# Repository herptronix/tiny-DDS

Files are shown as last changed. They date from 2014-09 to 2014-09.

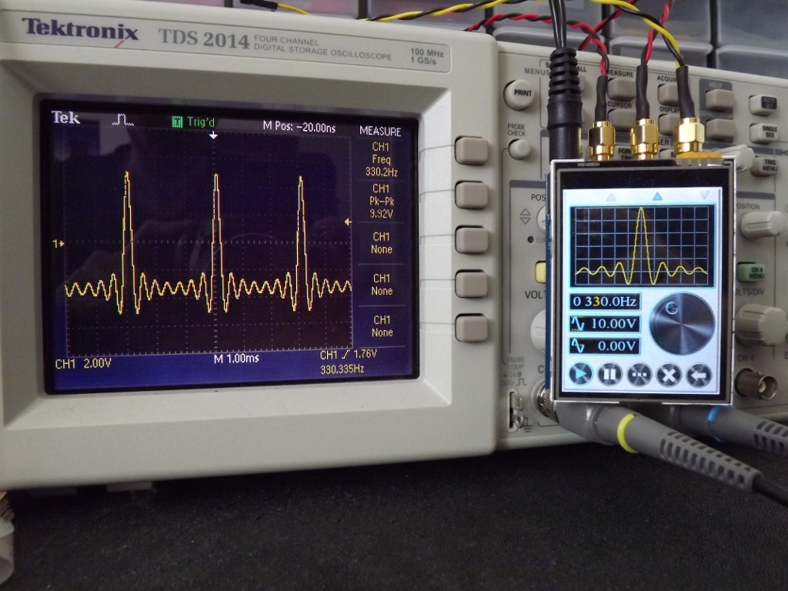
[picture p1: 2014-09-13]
documentation/dds.jpg

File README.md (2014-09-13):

Tiny DDS
================

Open source (hardware & software) DDS generator, based on:
 - smart TFT module
 - AD9834
 - LM7171 fast amplifier

Small video: https://www.youtube.com/watch?v=Hllg0D2UqWg
Some explanations (french only): http://herptronix.blogspot.fr/2014/08/tiny-dds.html



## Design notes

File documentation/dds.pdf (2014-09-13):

The homemade function generator is a quite common project on the internet. We can find different ways to do it:

- The quick & dirty way based on a DDS module bought on eBay
- The analog version based on a MAX038 / XR2206
- The “clean” way based on a FPGA and a fast DAC (e.g. http://www.circuitben.net/node/14)
- The software way (e.g. Arduino + R/2R DAC)

From my side, I wanted a small one which could fits my needs without being too expensive. According to me, such generator should at least:

- Be easy to use
- Output a signal from 1Vpp to 10Vpp (+/-5V), from 0 to 1MHz
- Have a low profile
- Without electric hazard (shall work on a 12V DC)

Choosing the DDS chip

I first started to look for a cheap DDS chip on eBay; you have to be careful because most of DDS chips have only a sinusoidal output. Since I also want a triangular output, I have chosen the AD9834. According to its datasheet, this component is able to output a frequency of 37.5MHz from a clock of 75MHz… But do not expect a clean waveform at such frequency: without an internal PLL, this signal would be defined by only 2 points.

From my personal experience, I consider that a waveform shall be defined by 10-20 points to be well restituted. Relying on a 75MHz clock, the maximal output frequency would be 7.5MHz… This is not a very good performance for a professional equipment (even if the cheapest generators do not go above 4MHz), but it is quite reasonable for a hobbyist project.

The AD9834 can be found at $5 on eBay.

Amplitude control

The amplitude of the AD9834 can be controlled through different ways:

- Constant amplitude of 1Vpp (by default on most COTS), by wiring a resistor between the FS_ADJUST pin and the ground: this is quite annoying because an additional external amplifier will be need to set the amplitude to a desired level.
- Variable amplitude, by wiring a potentiometer between the FS_ADJUST pin and the ground: this solution is really easy to implement, but it will not allow a software management needed, for example, by the amplitude modulation.
- Software variable amplitude, by wiring a DAC to the FS_ADJUST pin. This solution is a bit more complex, but it will allow to implement some useful functionalities. I choose this way.

The amplitude will be set by the microcontroller of the smart TFT module (PIC32MX795). Unlike the other manufacturers (Atmel, ST…), Microchip did not include a DAC on their $10 chip… An external DAC is needed (an AD5310 found on eBay for $0.8 – 10 bit / SPI, SOT23-6 package).
A small voltage divider is put between the DAC and the FS_ADJUST pin in order to transform the 0-3.3V of the DAC into 0-1.2V handled by the AD9834:

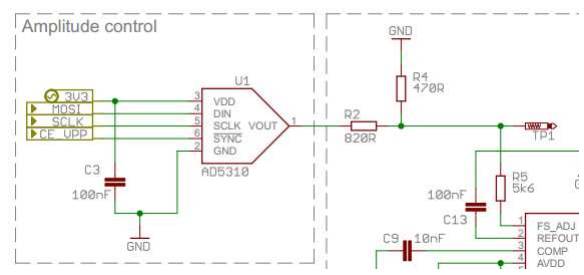
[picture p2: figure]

Notice: the logical levels are reversed: the minimal amplitude is reached when the DAC output is 3V3 and the maximal amplitude is reached when the DAC output is 0V.

AC coupling

The AD9834 generates a signal with a non-null offset, variable according to the amplitude. At this point, this offset is very annoying and shall be removed. Two possible ways:
- A high pass filter (a simple RC filter): this solution ensures an ideal AC coupling, but is problematic for the low frequency signals (a huge RC filter would be needed for frequencies below 100Hz)
- A differential amplifier: it is possible with the AD9834 because this component already has a differential output (IOUT / IOUTB pins). This solution makes the AC coupling effective even for very low frequencies, even for a DC signal. Therefore, the AC coupling will not be “ideal”: a small offset will be injected, and possibly some additional distortions due to the tolerance of the components (OPAMP & resistors). Nevertheless, it remains the best way according to me.

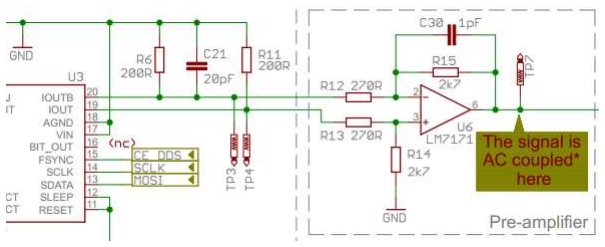
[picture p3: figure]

The ratio R15/R12 is set such as the maximal voltage outputted by U6 is +/-3.3V.

Offset control
Nothing difficult here: we just have to generate a DC signal between -3.3V and +3.3V. I use another AD5310 with a small OPAMP:

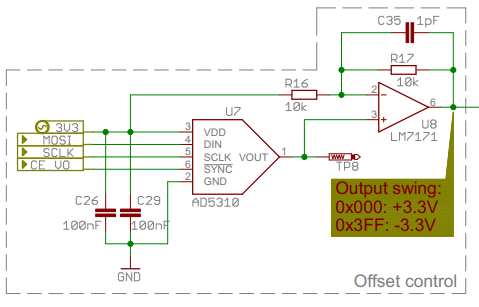
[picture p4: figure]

Notice: here again, the logical levels are reversed: the minimal offset is reached when the DAC output is +3.3V and the maximal offset is reached when the DAC output is 0V.

Final stage
Here, we have 2 signals: the one coming from the DDS (between -3.3V and +3.3V, AC coupled) and the one coming from the offset control (between -3.3V and +3.3V too). We just have to mix these 2 signals and amplify them to get a +/-5V output:

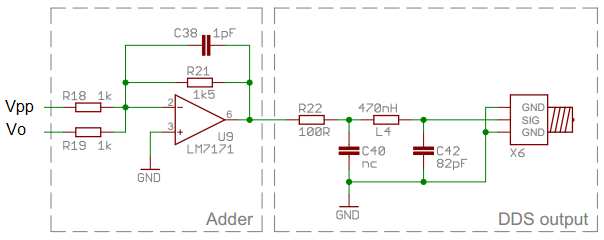
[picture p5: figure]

The LM7171 is able to output more than 100mA; nevertheless, the current is limited through a 100R resistor. A small LC filter is also implemented before the main output for filtering the 75MHz clock residual.

PWM output
Nothing complex here: a simple CMOS gate for buffering the PWM output of the microcontroller. I tried to use a fast comparator on the triangular output of the DDS, but the jitter was too important; I finally gave up this solution.

Analog input

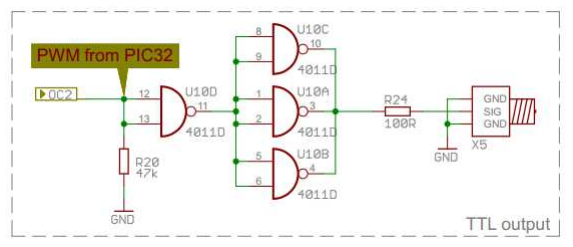
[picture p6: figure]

Very minimalist… A simple resistor for limiting the input current, and a common Pi filter. The sampling frequency is not very high (~ 1KHz) because the internal ADC of the microcontroller is also used by the touchscreen inside an ISR.

Power supply / regulators

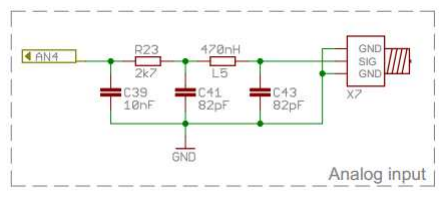
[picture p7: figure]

The generator is powered by a standard 12V plug. Some switching regulators produce the 5V (for the smart TFT module) and the +/-7V (used by the analog stage). The 3.3V comes directly from the smart TFT. The LT1616 are an expensive components on Farnell, but I found these on eBay for $0.8. Notice that any buck regulator should do the job here (+5V@200mA, +/-7V@200mA).

PCB
The whole schematic can be easily routed in a small PCB (smaller than a credit card). The PCB is composed of 2 layouts, with a common GND plan. The LM7171 shall be routed with care: due to its topology (fast OPAMP – 400MHz), a bad layout will make it oscillate. For this reason, I also add a footprint for a small 1pF capacitor: if the layout is not correct, I should be able to limit the oscillations with it.

Assembling the board
The PCBs (from SeeedFusion):

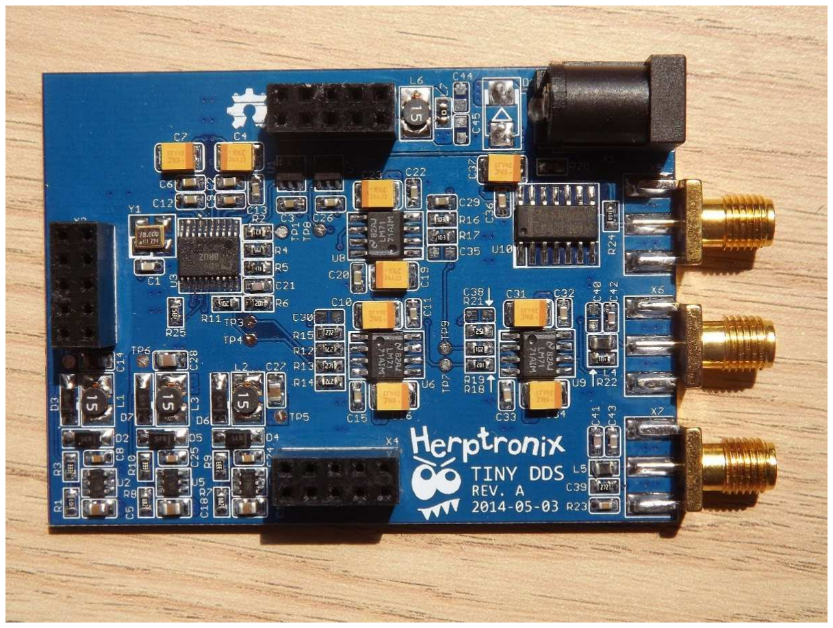
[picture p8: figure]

The finished board:

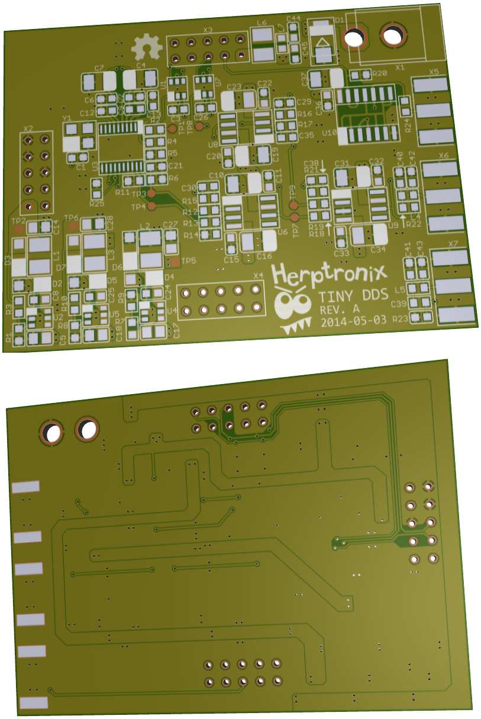
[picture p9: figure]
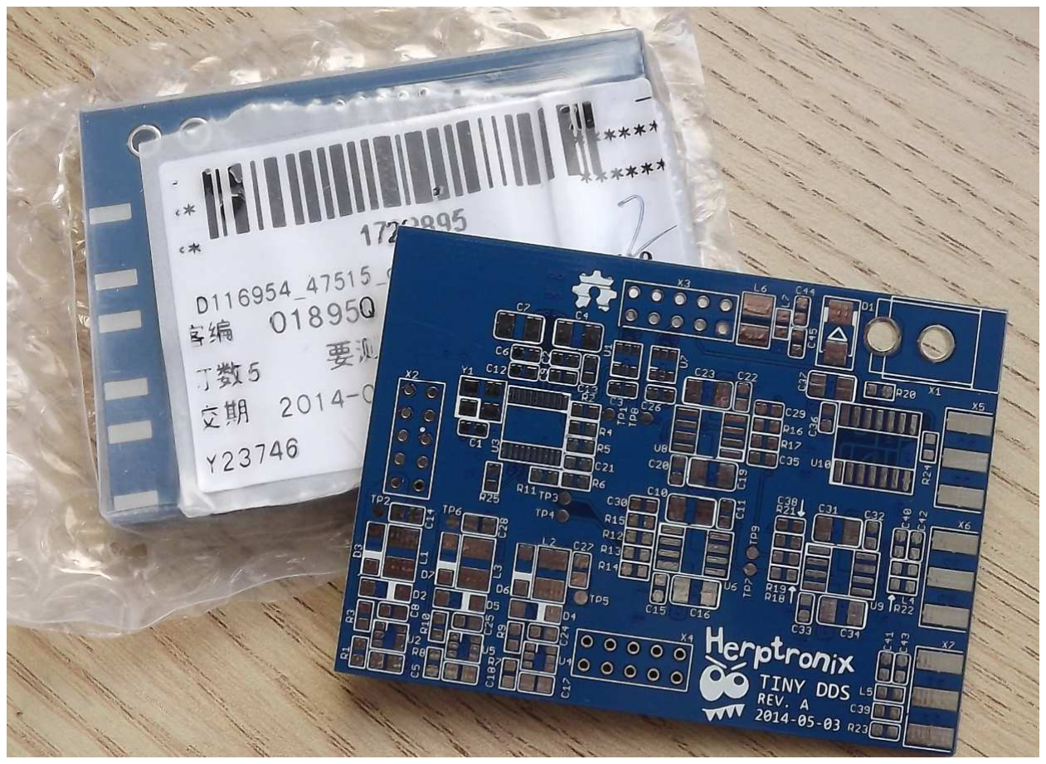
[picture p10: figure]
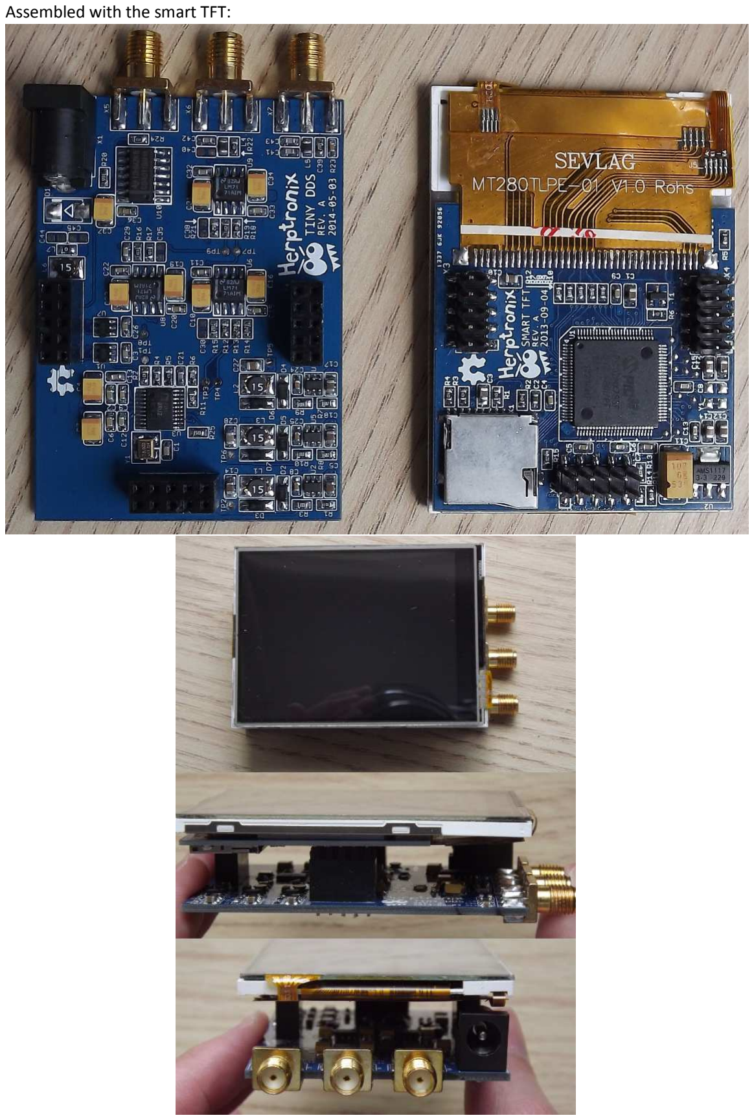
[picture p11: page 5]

Assembled with the smart TFT:

Software
After a first quick & dirty attempt, I had to enhance the interface look; this one is working properly, but I admit that the old win95 look is really outdated. Moreover, there is a flickering issue on some widgets which are highly solicited (e.g. the frequency valueBox).
The new interface is based on a brushed metal background, with dark widgets. I have also implemented the double buffering for the concerned widgets:

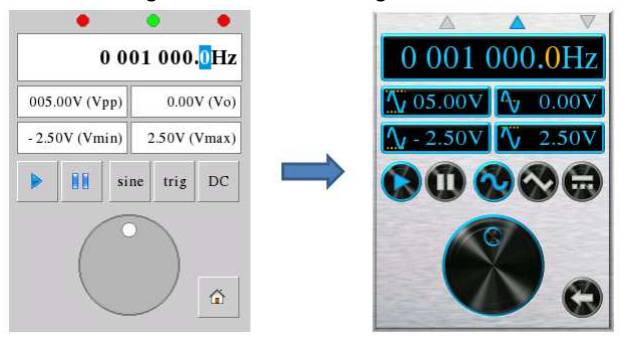
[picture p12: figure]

The new look is more modern (according to me; I’m not a graphic artist :s). The interface is still very reactive, but the memory footprint literally explodes (more than 90% of the flash memory is used). The user interface is composed of 4 “pages”:
- DDS (sinus/triangle waveform, with frequency / amplitude / offset control)
- PWM (PWM signal only)
- ARB (arbitrary waveforms & modulations)
- A menu page

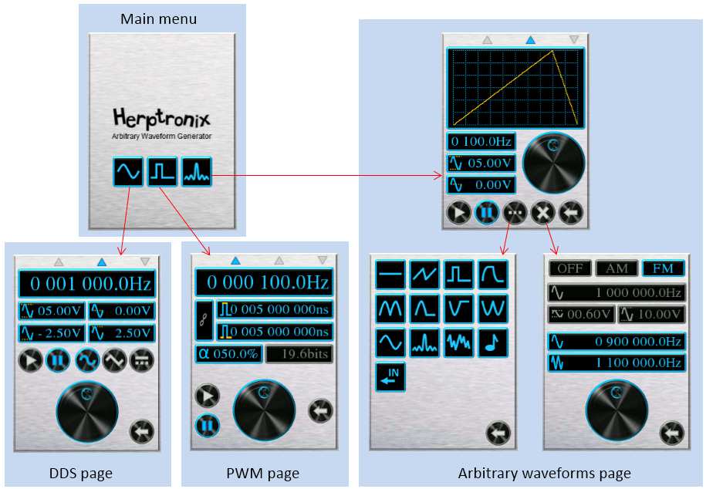
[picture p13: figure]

Sinus / triangle waveform generation
These waveforms are directly generated by the AD9834, just by configuring its internal registers through the SPI bus. Nevertheless, a small detail shall be handled by the program: the frequency register is coded on 28 bits, split on two 16 bits registers. The access to the frequency register is not an atomic operation and shall be buffered first (through the FREQ0 / FREQ1 registers).

Arbitrary waveforms generation
I use the internal DAC of the AD9834 to generate these signals: this solution allows to keep the whole analog stage as is (same amplitude / offset control). For using the internal DAC, I configure the AD9834 with a triangle signal of 0Hz; then, I set the phase register to obtain the desired output voltage.
Some basic waveforms are available, such as saw tooth, exponential, noise, sin(x)/x… It is also possible to draw a waveform and play a wav file.
However, there is a bandwidth issue: the AD9834 is accessed through a SPI bus, and even with a 20MHz clock, several microseconds are needed to send a single sample on the output. At the end, the microcontroller cannot provide more than 100kSPS (kilo Sample Per Second). Above this rate, the program is ran very slowly (most of the CPU time is spent into the ISR).

Go further
Even if this generator works properly, I have to admit that its electrical characteristics are closer to a gadget than a professional equipment (SNR below 45db). However, it would be easy to enhance its performances by modifying some components:
- The DDS chip
A DDS such as the AD9102 is much more powerful than the AD9834; besides its more accurate DAC (14bits vs 10bits), its internal LUT can be reprogrammed: where the PIC32 can only provide 100kSPS, the AD9102 can provide up to 180MSPS (1800 time more). Unfortunately, this device is more expensive ($15/u at 100u) and is available only in LFCSP package (quite hard to solder).
- The analog stage
The power supply should be changed first: the +/-7V coming from the buck regulators are obviously problematic (the output signal has some noise – 1.5MHz @10mVpp). A simple power supply based on a toroidal transformer and some 78xx / 79xx would be better.
The LM7171 OPAMPs should also be changed by a more appropriate chip (a current feedback OPAMP for example).
- DAC
The 10 bits of the AD5310 might not be the wisest solution for this application: for 10Vpp, 1LSB is equivalent to ~10mV, which is pretty good… if you use the whole range of the DAC! I reduced the range from 0-1023 to 0-920 due to the tolerance of the components, leading to an 11mV/LSB resolution. A 12 bits DAC would be a better solution here, thus a true voltage reference (the current one is derived from the 3.3V supply).

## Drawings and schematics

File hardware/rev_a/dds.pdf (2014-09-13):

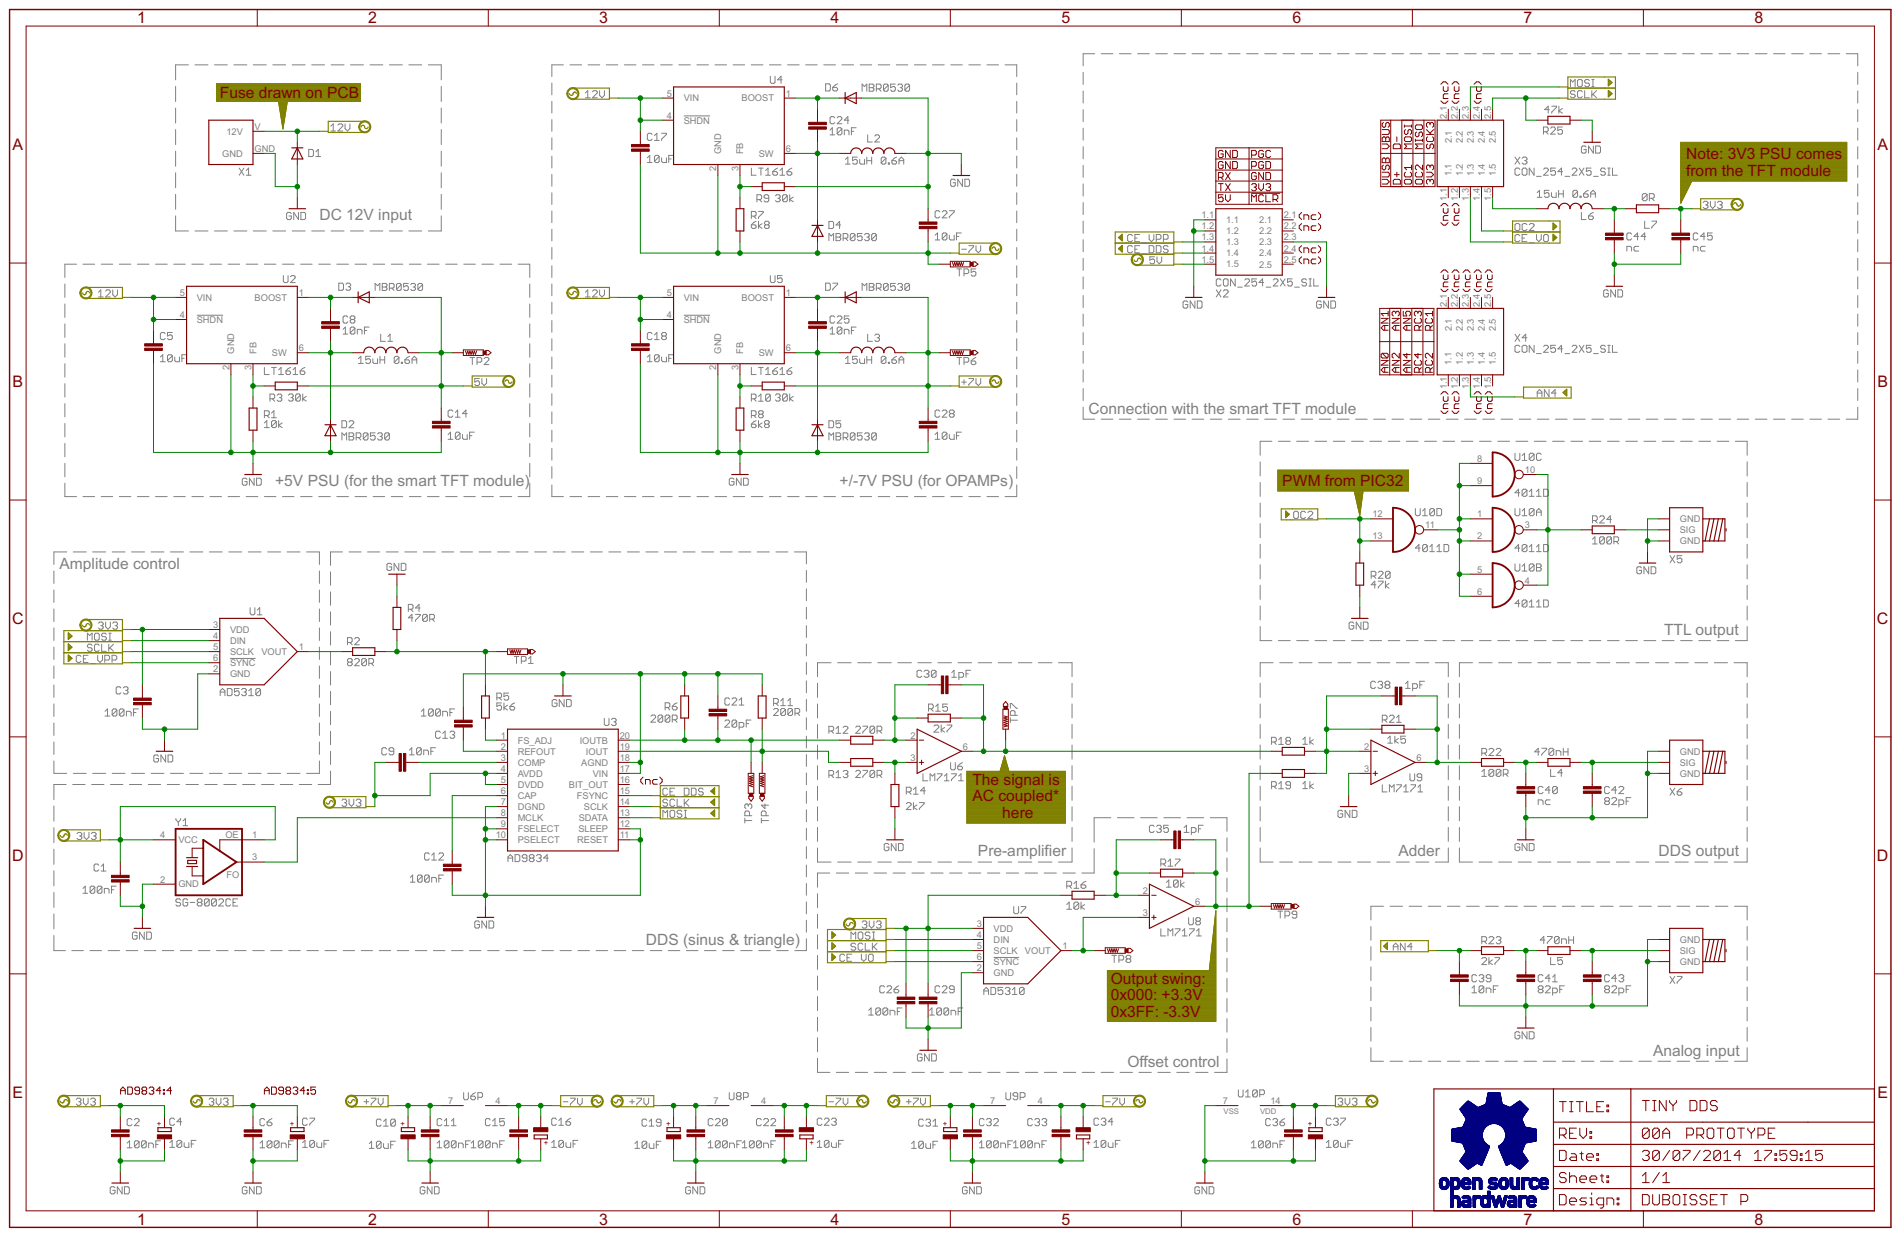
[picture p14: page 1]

Fuse drawn on PCB

Note: 3V3 PSU comes
from the TFT module

Connection with the smart TFT module

The signal is AC coupled* here

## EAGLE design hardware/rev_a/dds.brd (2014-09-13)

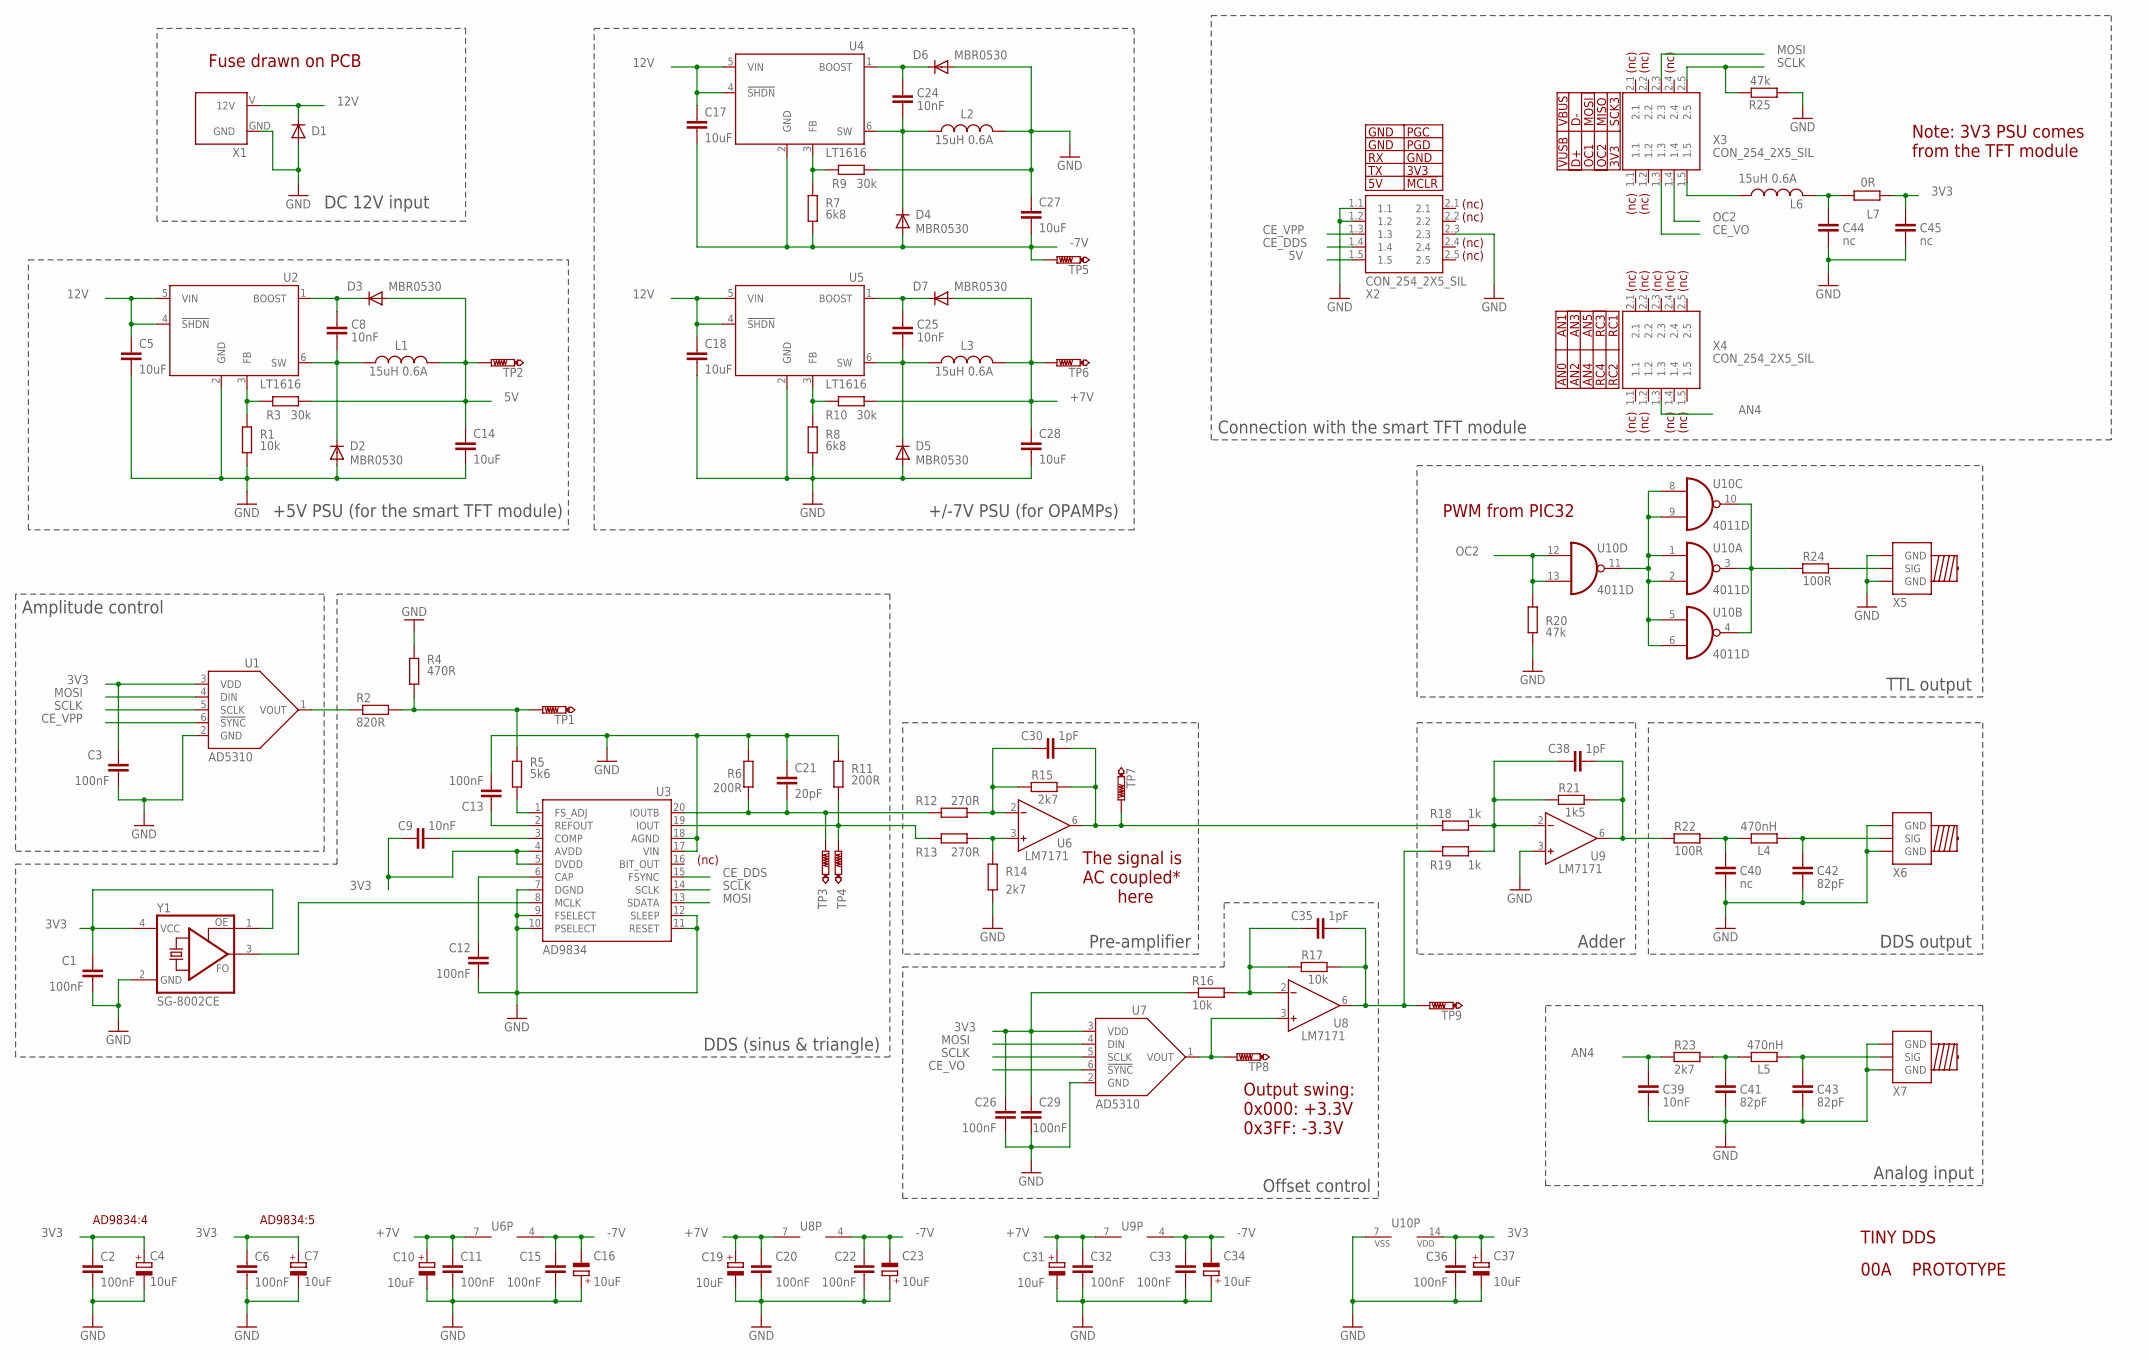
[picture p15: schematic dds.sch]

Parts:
C1, C2, C3, C6, C11, C12, C13, C15, C20, C22, C26, C29, C32, C33, C36: 100nF; C0603
C4, C7, C10, C16, C19, C23, C31, C34, C37: 10uF; SMC_B
C5, C14, C17, C18, C27, C28: 10uF; C0805
C8, C9, C24, C25, C39: 10nF; C0603
C21: 20pF; C0603
C30, C35, C38: 1pF; C0603
C40, C44, C45: nc; C0603
C41, C42, C43: 82pF; C0603
D1: DIODE-SMB; SMB
D2, D3, D4, D5, D6, D7: MBR0530; SOD123
L1, L2, L3, L6: 15uH 0.6A; L5X3
L4, L5: 470nH; R0603
L7: 0R; R0603
R1, R16, R17: 10k; R0603
R2: 820R; R0603
R3, R9, R10: 30k; R0603
R4: 470R; R0603
R5: 5k6; R0603
R6, R11: 200R; R0603
R7, R8: 6k8; R0603
R12, R13: 270R; R0603
R14, R15, R23: 2k7; R0603
R18, R19: 1k; R0603
R20, R25: 47k; R0603
R21: 1k5; R0603
R22, R24: 100R; R0603
TP1, TP2, TP3, TP4, TP5, TP6, TP7, TP8, TP9: PTR1B1,27; B1,27
U1, U7: AD5310; SOT23-6
U2, U4, U5: LT1616; SOT23-6
U3: AD9834; TSSOP20
U6, U9: LM7171; SO8
U8: LM7171; SO8; MPN AD811JRZ
U10: 4011D; SO14
X1: CON_12V
X2, X3, X4: CON_254_2X5_SIL; 2X5_SIL
X5, X6, X7: CON_SMA; SMA_SMD
Y1: SG-8002CE; ASF

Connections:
3V3: C1.1, C2.1, C3.1, C4.+, C6.1, C7.+, C9.2, C26.1, C29.1, C36.1, C37.+, C45.1, L7.2, R16.1, U1.3 (VDD), U3.4 (AVDD), U3.5 (DVDD), U7.3 (VDD), U10.14 (VDD), Y1.1 (OE), Y1.4 (VCC)
5V: C14.1, D3.A, L1.P$2, R3.1, TP2.TP, X2.1.5
12V: C5.1, C17.1, C18.1, D1.C, U2.4 (!SHDN), U2.5 (VIN), U4.4 (!SHDN), U4.5 (VIN), U5.4 (!SHDN), U5.5 (VIN), X1.V (12V)
+7V: C10.+, C11.1, C19.+, C20.1, C28.1, C31.+, C32.1, D7.A, L3.P$2, R10.1, TP6.TP, U6.7 (V+), U8.7 (V+), U9.7 (V+)
-7V: C15.1, C16.-, C17.2, C22.1, C23.-, C27.2, C33.1, C34.-, D4.A, R7.1, TP5.TP, U4.2 (GND), U6.4 (V-), U8.4 (V-), U9.4 (V-)
AN4: C39.1, R23.1, X4.1.3
CE_DDS: U3.15 (FSYNC), X2.1.4
CE_VO: U7.6 (!SYNC), X3.1.3
CE_VPP: U1.6 (!SYNC), X2.1.3
GND: C1.2, C2.2, C3.2, C4.-, C5.2, C6.2, C7.-, C10.-, C11.2, C12.2, C13.2, C14.2, C15.2, C16.+, C18.2, C19.-, C20.2, C21.1, C22.2, C23.+, C26.2, C27.1, C28.2, C29.2, C31.-, C32.2, C33.2, C34.+, C36.2, C37.-, C39.2, C40.2, C41.2, C42.2, C43.2, C44.2, C45.2, D1.A, D2.A, D5.A, D6.A, L2.P$2, R1.1, R4.1, R6.2, R8.1, R9.1, R11.2, R14.1, R20.1, R25.1, U1.2 (GND), U2.2 (GND), U3.7 (DGND), U3.9 (FSELECT), U3.10 (PSELECT), U3.11 (RESET), U3.12 (SLEEP), U3.17 (VIN), U3.18 (AGND), U5.2 (GND), U7.2 (GND), U9.3 (IN+), U10.7 (VSS), X1.GND, X2.1.1, X2.1.2, X2.2.3, X5.GND@1 (GND), X5.GND@2 (GND), X6.GND@1 (GND), X6.GND@2 (GND), X7.GND@1 (GND), X7.GND@2 (GND), Y1.2 (GND)
MOSI: U1.4 (DIN), U3.13 (SDATA), U7.4 (DIN), X3.2.3
unnamed: C21.2, R6.1, R12.1, TP3.TP, U3.20 (IOUTB)
unnamed: C13.1, U3.2 (REFOUT)
unnamed: C9.1, U3.3 (COMP)
unnamed: C8.1, D2.C, L1.P$1, U2.6 (SW)
unnamed: R11.1, R13.1, TP4.TP, U3.19 (IOUT)
unnamed: C12.1, U3.6 (CAP)
unnamed: U3.8 (MCLK), Y1.3 (FO)
unnamed: C30.1, R12.2, R15.1, U6.2 (IN-)
unnamed: R2.1, U1.1 (VOUT)
unnamed: C41.1, L5.1, R23.2
unnamed: R5.2, U3.1 (FS_ADJ)
unnamed: R13.2, R14.2, U6.3 (IN+)
unnamed: C30.2, R15.2, R18.1, TP7.TP, U6.6 (OUT)
unnamed: C40.1, L4.1, R22.2
unnamed: TP8.TP, U7.1 (VOUT), U8.3 (IN+)
unnamed: C35.1, R16.2, R17.1, U8.2 (IN-)
unnamed: C38.1, R18.2, R19.2, R21.1, U9.2 (IN-)
unnamed: C35.2, R17.2, R19.1, TP9.TP, U8.6 (OUT)
unnamed: C38.2, R21.2, R22.1, U9.6 (OUT)
unnamed: C8.2, D3.C, U2.1 (BOOST)
unnamed: C24.1, D4.C, L2.P$1, U4.6 (SW)
unnamed: C25.1, D5.C, L3.P$1, U5.6 (SW)
unnamed: R1.2, R3.2, U2.3 (FB)
unnamed: C25.2, D7.C, U5.1 (BOOST)
unnamed: R2.2, R4.2, R5.1, TP1.TP
unnamed: R8.2, R10.2, U5.3 (FB)
unnamed: C24.2, D6.C, U4.1 (BOOST)
unnamed: R7.2, R9.2, U4.3 (FB)
unnamed: C42.1, L4.2, X6.SIG
unnamed: C43.1, L5.2, X7.SIG
unnamed: U10.1 (I0), U10.2 (I1), U10.5 (I0), U10.6 (I1), U10.8 (I0), U10.9 (I1), U10.11 (O)
unnamed: R24.1, U10.3 (O), U10.4 (O), U10.10 (O)
unnamed: R24.2, X5.SIG
unnamed: C44.1, L6.P$2, L7.1
unnamed: L6.P$1, X3.1.5
OC2: R20.2, U10.12 (I0), U10.13 (I1), X3.1.4
SCLK: R25.2, U1.5 (SCLK), U3.14 (SCLK), U7.5 (SCLK), X3.2.5

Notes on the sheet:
PROTOTYPE
00A
TINY DDS
AD9834:4
AD9834:5
(nc)
GND
!MCLR
3V3
PGD
PGC
OC2
OC1
VUSB
SCK3
MISO
MOSI
VBUS
RC1
RC3
AN5
AN3
AN1
RC2
RC4
AN4
AN2
AN0
Connection with the smart TFT module
Note: 3V3 PSU comes
from the TFT module
TTL output
Analog input
Pre-amplifier
The signal is
AC coupled*
here
Offset control
Amplitude control
DDS output

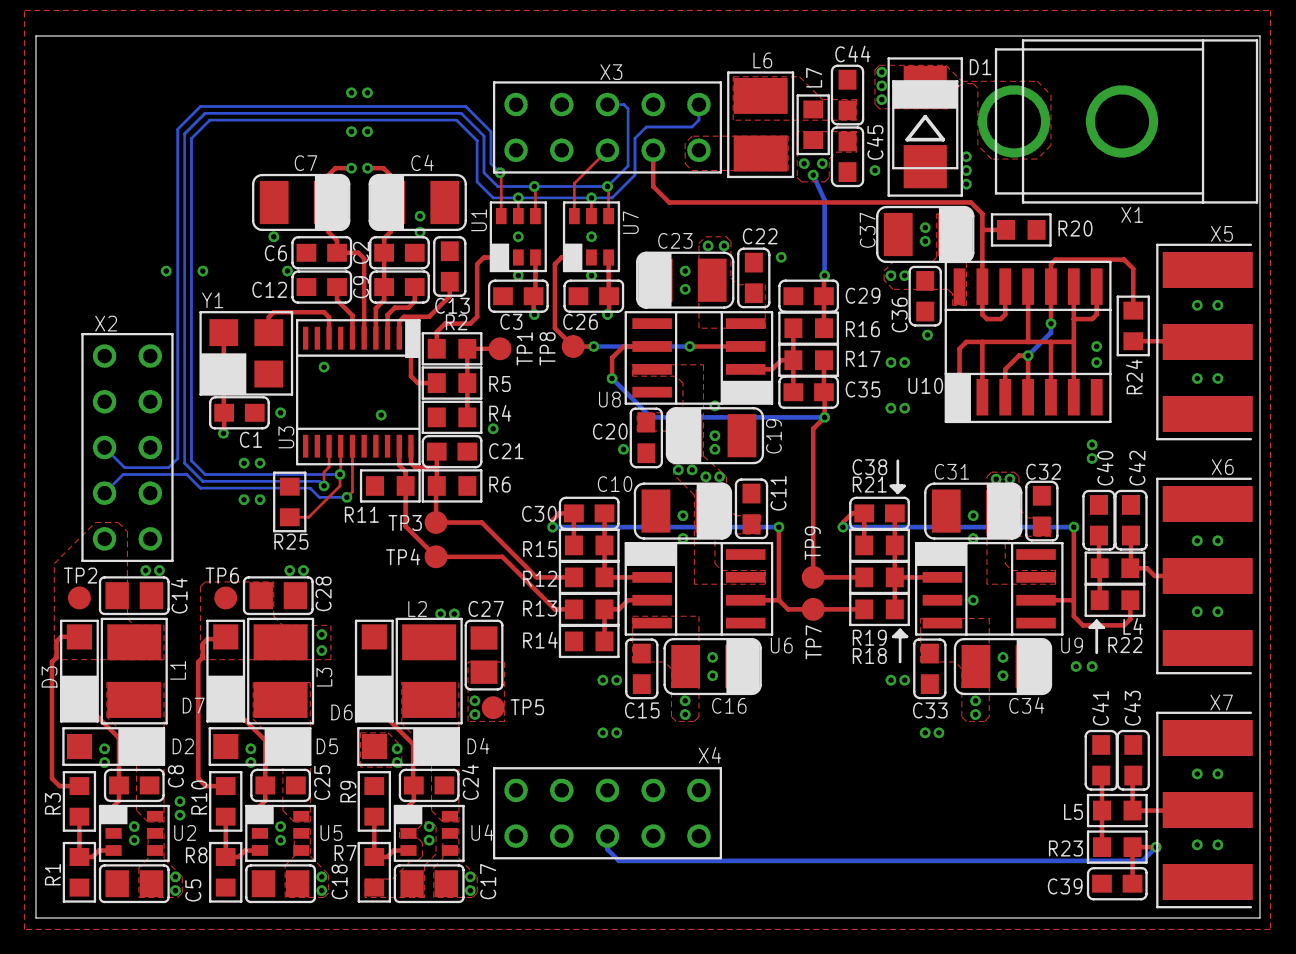
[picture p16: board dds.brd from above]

Board: 2 copper layers, 68.0 x 49.0 mm, 111 parts (0 on the bottom side), 48 nets.

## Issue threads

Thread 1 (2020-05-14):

Crystal oscillator details are missing in BOM.

AbidHussain70, 2020-05-14:
Hi,
I am preparing the BOM and I am confused i selecting Crystal **SG-8002CE** .
What should be the operating voltage and frequency for the crystal?

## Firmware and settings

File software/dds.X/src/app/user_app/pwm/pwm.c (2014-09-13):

/**
 * @file pwm.c
 * @brief pwm output management
 * @author Duboisset Philippe
 * @version 0.1b
 * @date (yyyy-mm-dd) 2014-04-05
 *
 * Copyright (C) <2014>  Duboisset Philippe <duboisset.philippe@gmail.com>
 *
 * This program is free software: you can redistribute it and/or modify
 * it under the terms of the GNU General Public License as published by
 * the Free Software Foundation, either version 3 of the License, or
 * any later version.
 * This program is distributed in the hope that it will be useful,
 * but WITHOUT ANY WARRANTY; without even the implied warranty of
 * MERCHANTABILITY or FITNESS FOR A PARTICULAR PURPOSE.  See the
 * GNU General Public License for more details.
 * You should have received a copy of the GNU General Public License
 * along with this program.  If not, see <http://www.gnu.org/licenses/>.
 */

#include "pwm.h"
#include <math.h>


/**
 * local variables
 */
static int32_t clock = 80000000;
static const uint32_t reg_max = 0xFFFFFFFF;


/**
 * local functions
 */
static void SetFrequency(pwm_ctrl_st *p);
static void SetTh(pwm_ctrl_st *p);
static void SetTl(pwm_ctrl_st *p);
static void SetDuty(pwm_ctrl_st *p);
static void UpdateDuty(pwm_ctrl_st *p);
static void UpdateResolution(pwm_ctrl_st *p);
static void UpdateFreq(pwm_ctrl_st *p);
static void UpdateTlTh(pwm_ctrl_st *p);


/**
 * @function PWM_Init
 * @brief initialize the PWM handler
 * @param pwm_ctrl_st *p: pwm handler
 * @param bool bFirstRun: if true, the handler will be fully cleared
 * @return none
 */
void PWM_Init(pwm_ctrl_st *p, bool bFirstRun) {

  if(bFirstRun == true && p != NULL) {

    memset(p, 0, sizeof(*p));

    /**hardware limitations*/
    p->dutyMin = 0;
    p->dutyMax = 1000;

    /*in Hz x 10*/
    p->freqMin = 5;
    p->freqMax = 10000000;

    /*in ns*/
    p->thMin = 0;
    p->thMax = 1000000000;
    p->tlMin = 0;
    p->tlMax = 1000000000;

    /*default: 100Hz, duty = 0.5, TH linked with TL*/
    p->duty = 500;
    p->freq = 1000;
    p->linkTlTh = 0;
  }

  PWM_Update(p, true);
}


/**
 * @function PWM_Run
 * @brief start the PWM generation
 * @param pwm_ctrl_st *p: pwm handler
 * @return none
 */
void PWM_Run(pwm_ctrl_st *p) {

  if(p != NULL && p->run == 0) {
    p->run = 1;
    #ifdef ARCH_PIC32
    OpenTimer23(T23_ON | T23_PS_1_1, p->tmrReg);
    OpenOC2(OC_ON | OC_TIMER2_SRC | OC_TIMER_MODE32 | OC_PWM_FAULT_PIN_DISABLE, p->thReg, 0);
    #endif
  }
}


/**
 * @function PWM_Stop
 * @brief stop the PWM generation
 * @param pwm_ctrl_st *p: pwm handler
 * @return none
 */
void PWM_Stop(pwm_ctrl_st *p) {
  #ifdef ARCH_PIC32
  CloseTimer23();
  #endif
  p->run = 0;
}


/**
 * @function PWM_Update
 * @brief looks for parameters modifications, then update hardware registers
 * @param pwm_ctrl_st *p: pwm handler
 * @param bool bForceUpdate: force refresh register
 * @return none
 */
void PWM_Update(pwm_ctrl_st *p, bool bForceUpdate) {

  if(p != NULL) {

    /*frequency modification*/
    if(p->freq != p->freqOld || bForceUpdate) {
      SetFrequency(p);
      SetDuty(p);
    }

    /*duty cycle modification*/
    else if(p->duty != p->dutyOld) {
      SetDuty(p);
    }

    /*TH modification*/
    else if(p->th != p->thOld) {
      SetTh(p);
      UpdateFreq(p);
      UpdateDuty(p);
    }

    /*TL modification*/
    else if(p->tl != p->tlOld) {
      SetTl(p);
      UpdateFreq(p);
      UpdateDuty(p);
    }

    /*register refresh*/
    if(p->run) {
      if(p->tmrRegOld != p->tmrReg) {
        #ifdef ARCH_PIC32
        PR2 = p->tmrReg;
        if(TMR2 >= p->tmrReg) TMR2 = 0;
        #endif
      }
      if(p->thRegOld != p->thReg || p->tlRegOld != p->tlReg) {
        #ifdef ARCH_PIC32
        SetDCOC2PWM(p->thReg);
        #endif
      }
    }

    /*compute actual values & save all*/
    UpdateTlTh(p);
    UpdateResolution(p);
    p->dutyOld = p->duty;
    p->freqOld = p->freq;
    p->thOld = p->th;
    p->tlOld = p->tl;
    p->tmrRegOld = p->tmrReg;
    p->thRegOld = p->thReg;
    p->tlRegOld = p->tlReg;
  }
}


/**
 * @function SetFrequency
 * @brief update registers according to new frequency value
 * @param pwm_ctrl_st *p: pwm handler
 * @return none
 */
static void SetFrequency(pwm_ctrl_st *p) {

  /*get the closest TMR value according to the desired freq*/
  p->tmrReg = clock * 10 / p->freq;

  /*the user increment is too small -> direclty +1/-1 the TMR*/
  if(p->tmrReg == p->tmrRegOld) {
    if(p->freq > p->freqOld && p->tmrReg > 1) p->tmrReg--;
    else if(p->tmrReg < reg_max) p->tmrReg++;
  }

  /*compute the final "real" frequency, based on TMR register*/
  p->freq = clock * 10 / p->tmrReg;
}


/**
 * @function SetTh
 * @brief update registers according to new TH value
 * @param pwm_ctrl_st *p: pwm handler
 * @return none
 */
static void SetTh(pwm_ctrl_st *p) {

  uint64_t tmp;

  /*compute the th register value, according to user input*/
  tmp = (uint64_t)p->th * clock / 1e9;
  if(tmp > reg_max) tmp = reg_max;
  p->thReg = (uint32_t) tmp;

  /*the user increment is too small -> direclty +1/-1 the TH reg*/
  if(p->thReg == p->thRegOld) {
    if(p->th < p->thOld && p->thReg > 0) p->thReg--;
    else if(p->thReg < reg_max) p->thReg++;
  }

  /*linked with TL?*/
  if(p->linkTlTh) {
    /*ensure that th <= treg, then deduce tl*/
    if(p->thReg > p->tmrReg) p->thReg = p->tmrReg;
    p->tlReg = p->tmrReg - p->thReg;
  }
  else {
    /*ensure that th+tl < regmax && th+tl > 0*/
    if((uint64_t)p->thReg + p->tlReg > reg_max) p->tlReg = reg_max - p->thReg;
    else if((uint64_t)p->thReg + p->tlReg == 0) p->thReg = 1;
  }
}


/**
 * @function SetTl
 * @brief update registers according to new TL value
 * @param pwm_ctrl_st *p: pwm handler
 * @return none
 */
static void SetTl(pwm_ctrl_st *p) {

  uint64_t tmp;

  /*compute the th register value, according to user input*/
  tmp = (uint64_t)p->tl * clock / 1e9;
  if(tmp > reg_max) tmp = reg_max;
  p->tlReg = (uint32_t) tmp;

  /*the user increment is too small -> direclty +1/-1 the TL reg*/
  if(p->tlReg == p->tlRegOld) {
    if(p->tl < p->tlOld && p->tlReg > 0) p->tlReg--;
    else if(p->tlReg < reg_max) p->tlReg++;
  }

  /*linked with TL?*/
  if(p->linkTlTh) {
    /*ensure that tl <= treg, then deduce th*/
    if(p->tlReg > p->tmrReg) p->tlReg = p->tmrReg;
    p->thReg = p->tmrReg - p->tlReg;
  }
  else {
    /*ensure that th+tl < regmax && th+tl > 0*/
    if((uint64_t)p->tlReg + p->thReg> reg_max) p->thReg = reg_max - p->tlReg;
    else if((uint64_t)p->thReg + p->tlReg == 0) p->tlReg = 1;
  }
}


/**
 * @function SetDuty
 * @brief update registers according to new duty cycle value
 * @param pwm_ctrl_st *p: pwm handler
 * @return none
 */
static void SetDuty(pwm_ctrl_st *p) {
  uint64_t tmp;
  tmp = (uint64_t)p->duty * p->tmrReg / 1000; /*duty is between 0-1000*/
  p->thReg = (uint32_t)tmp;
  p->tlReg = p->tmrReg - p->thReg;
}
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

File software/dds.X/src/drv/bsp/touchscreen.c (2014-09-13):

/**
 * @file touchscreen.c
 * @brief resistive touchscreen driver
 * @author Duboisset Philippe
 * @version based on 0.4b (modification not checked) 2014-04-05
 * @date (yyyy-mm-dd)
 * 2013-07-13 initial version
 * 2013-09-22 modification of TouchScreenCalib(NULL)
 * 2013-09-26 modification to avoid the parasit capacitance error
 * 2014-02-20 support of display orientation (0, 90, 180, 270°)
 *
 * Copyright (C) <2013>  Duboisset Philippe <duboisset.philippe@gmail.com>
 *
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
 * You should have received a copy of the GNU General Public License
 * along with this program.  If not, see <http://www.gnu.org/licenses/>.
 */

#include "touchscreen.h"
#include "adc.h"
#include "gpio.h"
#include "sem.h"
#include "tmr.h"

#define X_P_PORT    B
#define X_P_PIN     8
#define X_N_PORT    B
#define X_N_PIN     10
#define Y_P_PORT    B
#define Y_P_PIN     9
#define Y_N_PORT    B
#define Y_N_PIN     11
#define ANA_IN_PIN  4

#define NB_SAMPLE         6   /*number of sample for filtering; shall be >= 2 to make the filter effective*/
#define TOUCH_TRIG        100 /*touch detection threeshold; empiric value*/
#define SAMPLE_TOLERANCE  12  /*tolerance between successive samples; empiric value*/

volatile uint16_t analogInputAdc = 0;

/*
 * Local functions
 */
static void FlushSamples(void);
static uint16_t Delta(uint16_t a, uint16_t b);
static uint16_t Average(volatile uint16_t *p, uint8_t nbSample);
static void TouchScreenIsr(void);

/*
 * Static variable used by the touchscreen ISR
 */
static volatile uint16_t xRead[NB_SAMPLE], yRead[NB_SAMPLE];
static volatile uint8_t state, posSample;
static volatile sem_t sem;
static volatile bool bTouch;

/*
 * Static variable used for calibration
 */
static float cx = 0.0f;
static float ox = 0.0f;
static float cy = 0.0f;
static float oy = 0.0f;



/**
 * @function TouchScreenEnable
 * @brief turn ON the touchscreen; overwrite ADC & TMR3 configuration
 * @param none
 * @return none
 */
void TouchScreenEnable(void) {

  GPIO_SetPin(Y_N_PORT, Y_N_PIN, 0);      /*preconfigured for 0V  output*/
  GPIO_SetPin(Y_P_PORT, Y_P_PIN, 1);      /*preconfigured for 3V3 output*/
  GPIO_SetPin(X_N_PORT, X_N_PIN, 0);      /*preconfigured for 0V  output*/
  GPIO_SetPin(X_P_PORT, X_P_PIN, 1);      /*preconfigured for 3V3 output*/
  GPIO_SetPinMode(Y_P_PIN, GPIO_ANALOG);  /*Y_P_PIN as analog input or digital output*/
  GPIO_SetPinMode(X_P_PIN, GPIO_ANALOG);  /*X_P_PIN as analog input or digital output*/
  GPIO_SetPinMode(ANA_IN_PIN, GPIO_ANALOG);
  ADC_Init();

  /*variable init.*/
  FlushSamples();
  state = 0;
  bTouch = false;
  sem = SEM_UNLOCKED;

  /*set up & run touchscreen ISR @ 4kHz*/
  TmrSetFrequency(TMR_4, 4000);
  TmrSetCallback(TMR_4, TouchScreenIsr);
  TmrLaunch(TMR_4);
}


/**
 * @function ANA_GetInput
 * @brief return the analog value of AN4 (between 0 -0xFFFF)
 * @param none
 * @return AN4 (between 0 -0xFFFF)
 */
uint16_t ANA_GetInput(void) {
  return analogInputAdc;
}


/**
 * @function TouchScreenDisable
 * @brief turn OFF the touchscreen
 * @param none
 * @return none
 */
void TouchScreenDisable(void) {

  /*kill touchscreen ISR*/
  TmrStop(TMR_4);

  /*consider touchscreen as released if disabled*/
  bTouch = false;

  /*release plate polarization, if any*/
  GPIO_SetPinDirection(X_N_PORT, X_N_PIN, GPIO_PIN_INPUT);
  GPIO_SetPinDirection(X_P_PORT, X_P_PIN, GPIO_PIN_INPUT);
  GPIO_SetPinDirection(Y_N_PORT, Y_N_PIN, GPIO_PIN_INPUT);
  GPIO_SetPinDirection(Y_P_PORT, Y_P_PIN, GPIO_PIN_INPUT);
}


/**
 * @function TouchScreenIsPressed
 * @brief return the touch screen state
 * @param none
 * @return bool: true if touched, false otherwise
 */
bool TouchScreenIsPressed(void) {
  return bTouch;
}


/**
 * @function TouchScreenReadRaw
 * @brief read the touchscreen filtered raw data
 * @param uint16_t *x, *y: x & y coordinate, in range[0 - (ADC_MAX_VALUE-1)]; ADC_RAW_ERR if touchscreen released
 * @return none
 */
void TouchScreenReadRaw(uint16_t *x, uint16_t *y) {

  static uint16_t oldX = ADC_MAX_VALUE, oldY = ADC_MAX_VALUE;
  uint16_t avgX, avgY, cnt;
  bool bBounce = false;

  if(x != NULL && y != NULL) {

    /*lock touchscreen ISR*/
    SemLock(sem);

    /*check if the touchscreen is actually pressed*/
    if(bTouch == true) {

      /*compute average x & y*/
      avgX = Average(xRead, NB_SAMPLE);
      avgY = Average(yRead, NB_SAMPLE);

      /*check if a sample is not too far (possible bounces issue)*/
      for(cnt = 0; bBounce == false && cnt < NB_SAMPLE; cnt++) {
        if(Delta(avgX, xRead[cnt]) > SAMPLE_TOLERANCE) bBounce = true;
        if(Delta(avgY, yRead[cnt]) > SAMPLE_TOLERANCE) bBounce = true;
      }
      /*if no bounce issue, return the new point*/
      if(bBounce == false) {
        *x = avgX;
        *y = avgY;
      }
      /*if bounce issue and screen still pressed, return the previous point*/
      else {
        *x = oldX;
        *y = oldY;
      }
    }
    else {
      *x = ADC_RAW_ERR;
      *y = ADC_RAW_ERR;
    }

    /*always save current result*/
    oldX = *x;
    oldY = *y;

    /*release ISR*/
    SemUnlock(sem);
  }
}


/**
 * @function TouchScreenRead
 * @brief read the touchscreen filtered coordinate (relative to screen dimension)
 * @param coord_t *x: range[0 - LCD_GetWidth()-1]; -1 if touchscreen released
 * @param coord_t *y: range[0 - LCD_GetHeight()-1]; -1 if touchscreen released
 * @return none
 */
void TouchScreenRead(coord_t *x, coord_t *y) {

  uint16_t xt, yt;

  if(x != NULL && y != NULL) {

    /*read touchscreen raw*/
    TouchScreenReadRaw(&xt, &yt);

    /*touchscreen pressed*/
    if(xt != ADC_MAX_VALUE && yt != ADC_MAX_VALUE) {

      /*convert x & y*/
      *x = (coord_t) (cx*xt + ox);
      *y = (coord_t) (cy*yt + oy);

      /*check overlap*/
      if(*x < 0) *x = 0;
      else if(*x >= LCD_GetWidth()) *x = LCD_GetWidth() - 1;
      if(*y < 0) *y = 0;
      else if(*y >= LCD_GetHeight()) *y = LCD_GetHeight() - 1;
    }
    /*touchscreen released*/
    else {
      *x = -1;
      *y = -1;
    }
  }
}
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
